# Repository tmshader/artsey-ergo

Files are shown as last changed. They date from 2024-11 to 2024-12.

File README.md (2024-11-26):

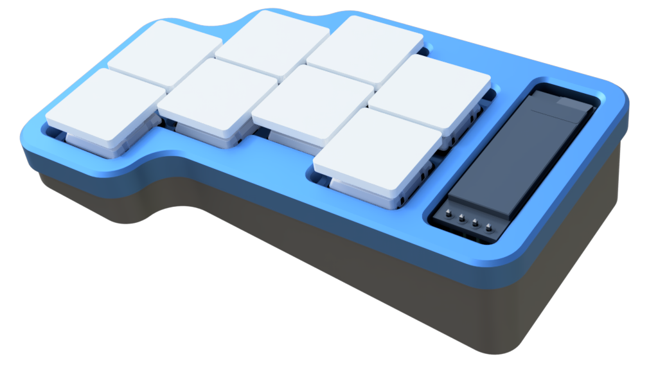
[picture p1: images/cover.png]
Artsey Ergo


# Artsey Ergo
A 3D printable ergonomic wireless Artsey-based keyboard running ZMK.

## Features:
- NRF52840 chip for fast communication over BLE
- USB-C for charging, updating and communication instead of BLE
- Slightly modified Artsey 9.0.0 layout
- 128x32 OLED display for layers, battery status, time and other fun stuff
- Hotswappable choc v1 swiches
- Easily printable case

## Try or modify the project

Modify `ergogen/config.yaml` or use the provided config.

Run ergogen to create the base files:
```bash
ergogen ./ergogen -o .
```

This creates an `outlines` and a `pcbs` folder:
- The `pcbs` folder contains the starting point from which we can start routing and modifying the board.
- The `outlines` folder contains a bunch of mechanical drawings in `.dxf` format but the most important for us is `cad.dxf` which we can import into our favourite CAD software (Fusion, FreeCAD, Solidworks, etc.) and start designing a case for the keyboard.

## Upcoming changes
- Choc and MX compatible board versions
- Using the NRF52840 chip instead of a module
- Thread and Zigbee support (why not?)
- OTA Updates

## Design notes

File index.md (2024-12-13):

---
layout: home
---

{% assign cacheBust = site.time | date:'?v=%s' %}








## Table of contents
{: .no_toc}

* TOC
{:toc}

## Renders

### Render Angled



### Render Top



### Render Bottom



## Schematic

### Monochrome

- [Schematic Monochrome PDF]({{ "/documents/artsey_ergo-schematic-mono.pdf" | absolute_url | append: cacheBust }})

### Light

- [Schematic Light PDF]({{ "/documents/artsey_ergo-schematic-default.pdf" | absolute_url | append: cacheBust }})

## Assembly

### Gerber viewer on tracespace.io

[JLCPCB Gerber](https://tracespace.io/view/?boardUrl={{ "export/artsey_ergo-JLCPCB.zip" | absolute_url | append: cacheBust }})

[Panelized JLCPCB Gerber](https://tracespace.io/view/?boardUrl={{ "export/artsey_ergo-panel-JLCPCB.zip" | absolute_url | append: cacheBust }})

### Interactive BOM

Check component locations by hovering over a specific component.
The visual elements might not be precise enough for pcb review but can be very useful since it's possible to pan and zoom.
Not all BOM columns are available here, for datasheet links see BOM below.

[IBOM HTML]({{ "/export/artsey_ergo-ibom.html" | absolute_url | append: cacheBust }})

### BOM

All components with Values, References, Sheetpath and Links to the datasheet.

[BOM HTML]({{ "/export/artsey_ergo-bom.html" | absolute_url | append: cacheBust }})

## Downloads

### JLCPCB

- [JLCPCB Zip]({{ "export/artsey_ergo-JLCPCB.zip" | absolute_url | append: cacheBust }})
- [JLCPCB BOM CSV]({{ "export/artsey_ergo_bom_jlc.csv" | absolute_url | append: cacheBust }})
- [JLCPCB CPL CSV]({{ "export/artsey_ergo_cpl_jlc.csv" | absolute_url | append: cacheBust }})

### Panelized JLCPCB

- [Panelized JLCPCB Zip]({{ "export/artsey_ergo-panel-JLCPCB.zip" | absolute_url | append: cacheBust }})
- [Panelized JLCPCB BOM CSV]({{ "export/artsey_ergo-panel_bom_jlc.csv" | absolute_url | append: cacheBust }})
- [Panelized JLCPCB CPL CSV]({{ "export/artsey_ergo-panel_cpl_jlc.csv" | absolute_url | append: cacheBust }})

### 3D Step

- [3D Step]({{ "/artsey_ergo-3D.step" | absolute_url | append: cacheBust }})

## Report

### ERC

{% include_relative erc_validation.md %}

### DRC

{% include_relative drc_validation.md %}

{% include_relative artsey_ergo-report.md %}

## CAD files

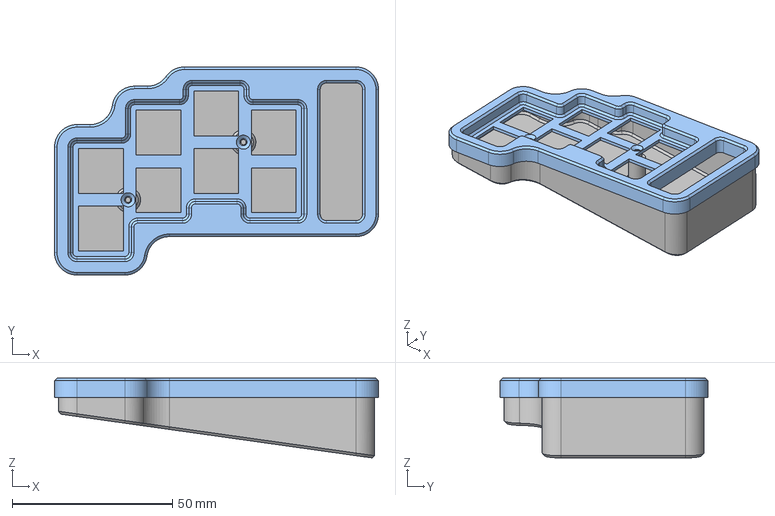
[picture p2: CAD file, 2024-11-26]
hardware/mechanical/STEPs/ArtseyErgo.step
101.2 x 65.0 x 24.9 mm

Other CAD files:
hardware/mechanical/STLs/ArtseyErgo.stl

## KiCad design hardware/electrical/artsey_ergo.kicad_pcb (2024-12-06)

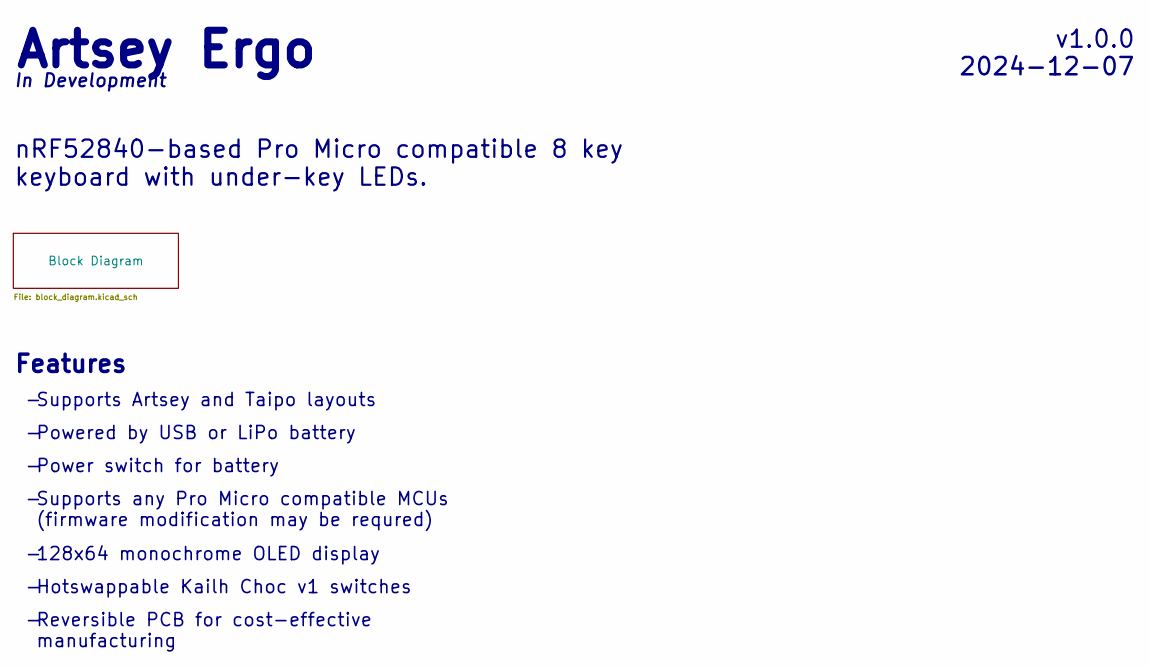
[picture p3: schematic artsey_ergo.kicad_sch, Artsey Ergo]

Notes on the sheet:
Features
Hotswappable Kailh Choc v1 switches
${REVISION}
${ISSUE_DATE}
128x64 monochrome OLED display
Supports any Pro Micro compatible MCUs (firmware modification may be requred)
Supports Artsey and Taipo layouts
${TITLE}
nRF52840-based Pro Micro compatible 8 key keyboard with under-key LEDs.
Powered by USB or LiPo battery
In Development
Reversible PCB for cost-effective manufacturing
Power switch for battery

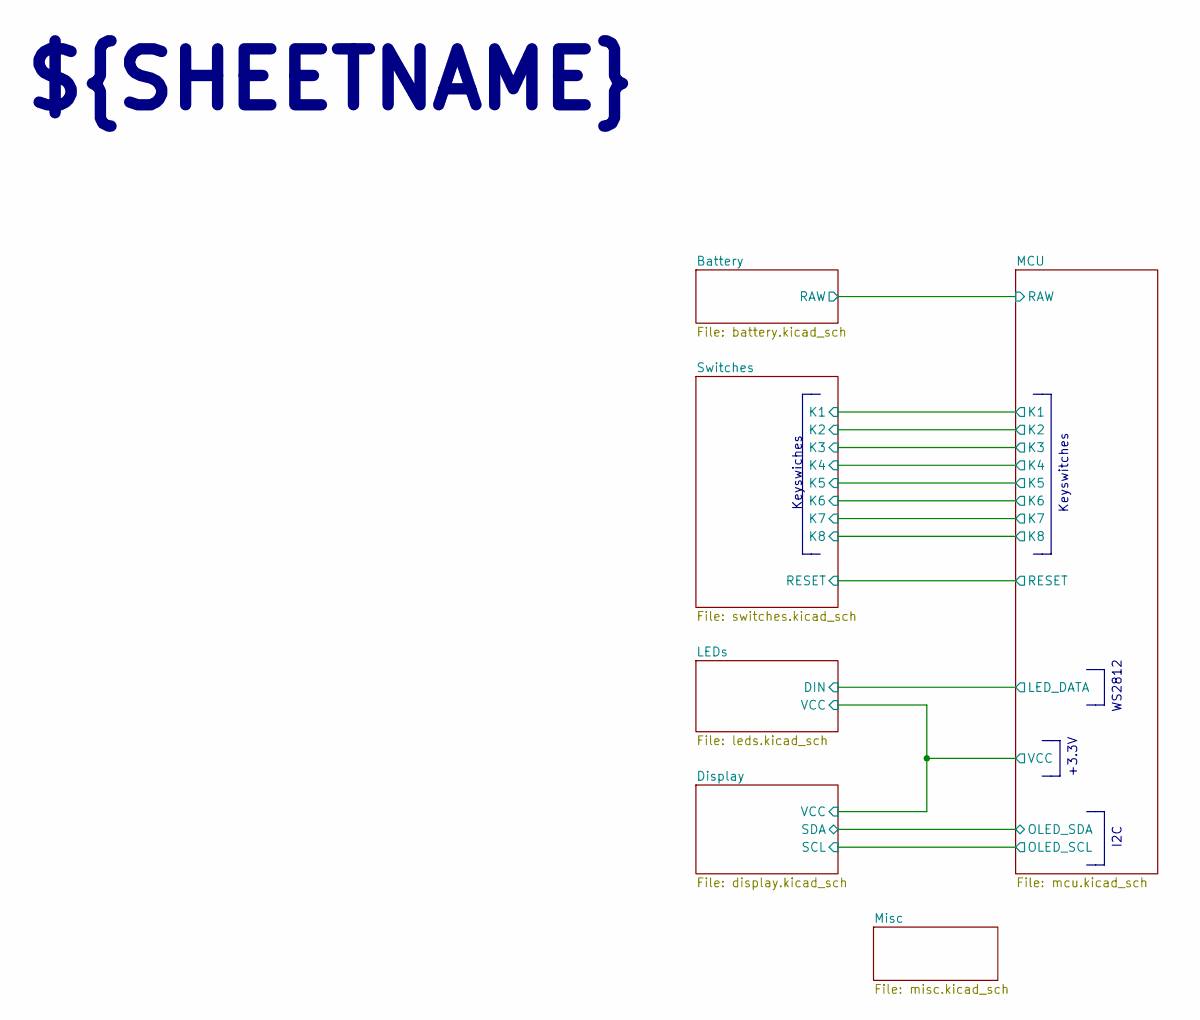
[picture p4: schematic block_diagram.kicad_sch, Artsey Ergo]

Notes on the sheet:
I2C
Keyswiches
+3.3V
${SHEETNAME}
Keyswitches
WS2812

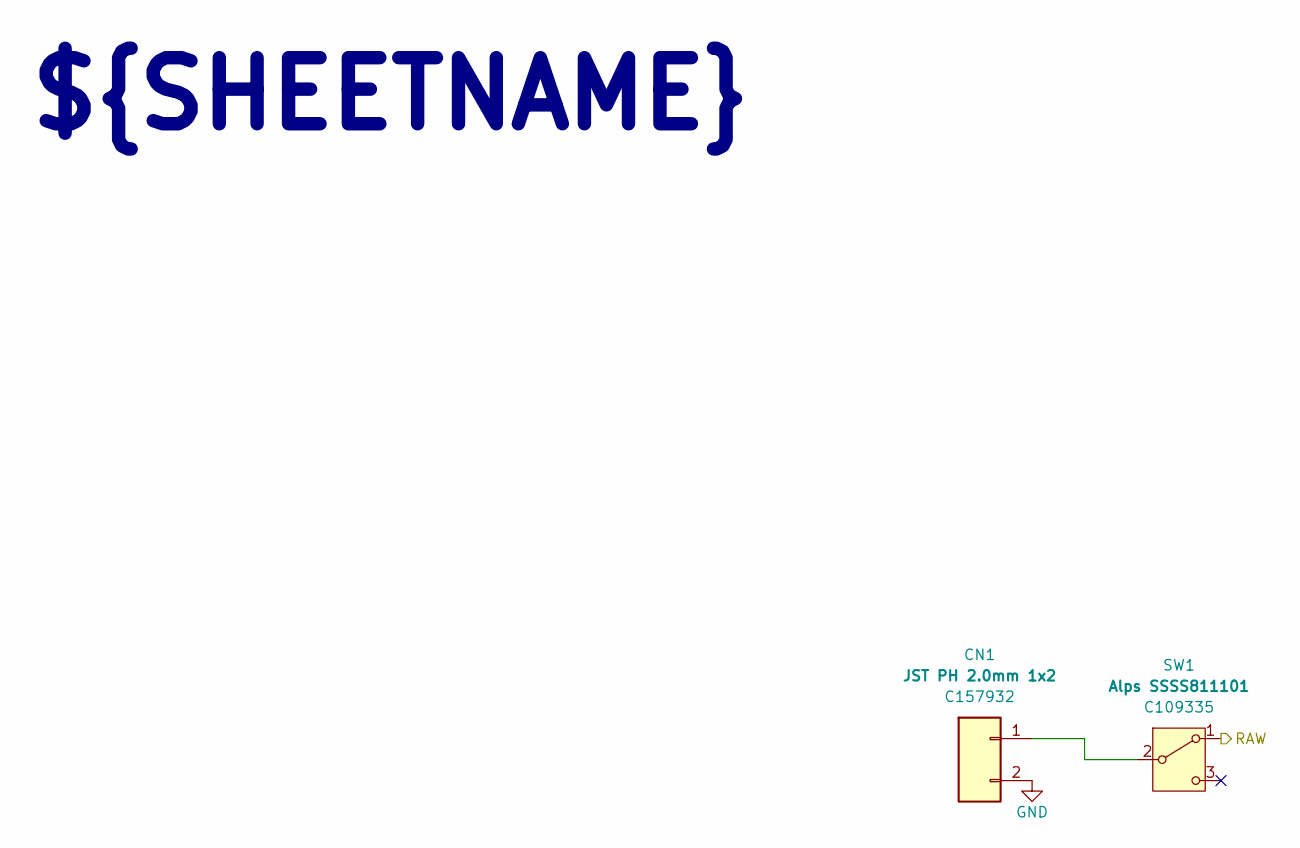
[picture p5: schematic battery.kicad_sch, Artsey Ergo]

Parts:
CN1: JST PH 2.0mm 1x2; battery_connector_jst_ph_2; LCSC C157932
SW1: Alps SSSS811101; power_switch_smd_side; LCSC C109335

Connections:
/Block Diagram/Battery/RAW: SW1.1 (A); also elsewhere on the board
GND: CN1.2; also elsewhere on the board
unnamed: CN1.1, SW1.2 (B)

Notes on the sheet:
${SHEETNAME}

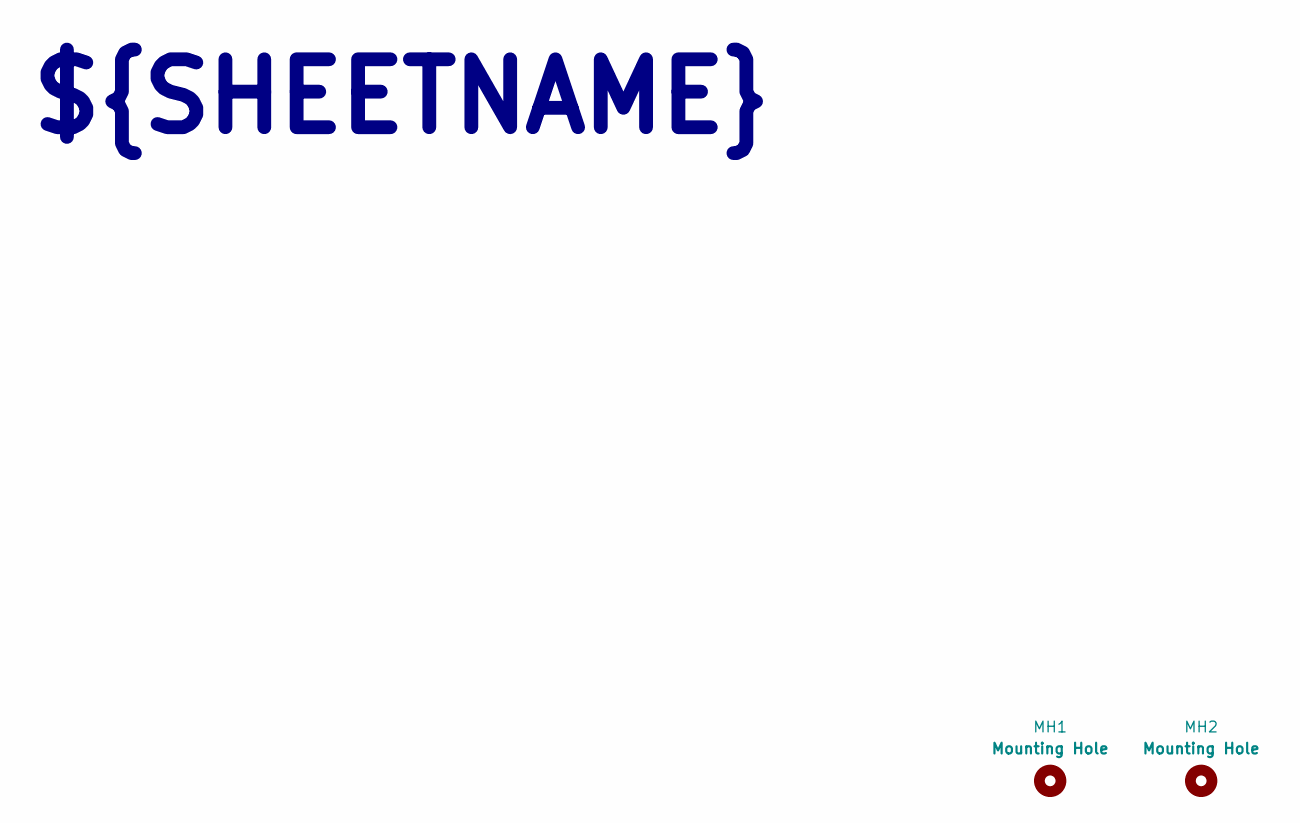
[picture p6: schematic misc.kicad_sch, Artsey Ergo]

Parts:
MH1, MH2: Mounting Hole; mounting_hole

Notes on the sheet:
${SHEETNAME}

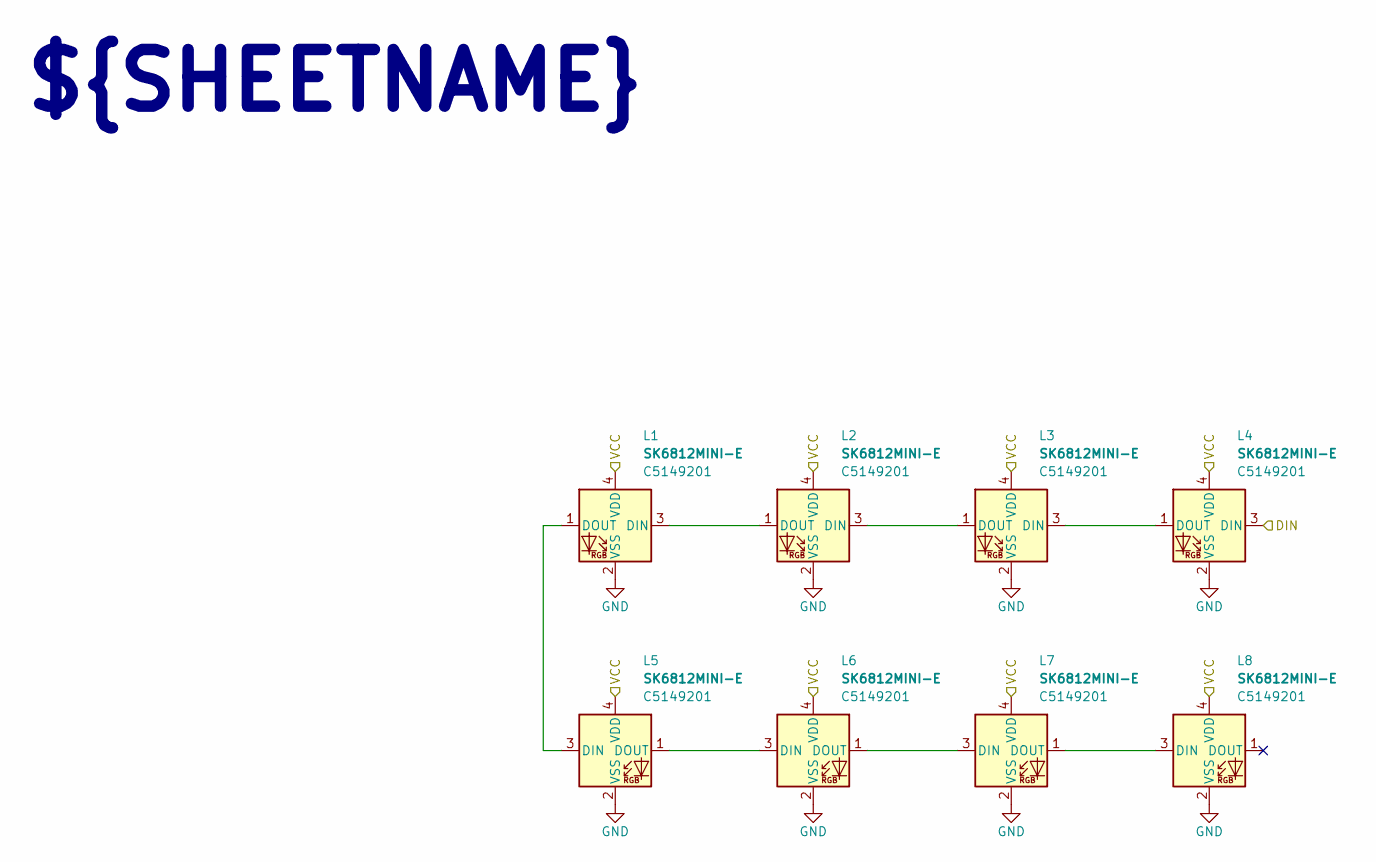
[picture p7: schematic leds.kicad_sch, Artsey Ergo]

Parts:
L1, L2, L3, L4, L5, L6, L7, L8: SK6812MINI-E; led_SK6812mini-e (per-key, reversible); LCSC C5149201

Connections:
/Block Diagram/Display/VCC: L1.4 (VDD), L2.4 (VDD), L3.4 (VDD), L4.4 (VDD), L5.4 (VDD), L6.4 (VDD), L7.4 (VDD), L8.4 (VDD); also elsewhere on the board
/Block Diagram/LEDs/DIN: L4.3 (DIN); also elsewhere on the board
GND: L1.2 (VSS), L2.2 (VSS), L3.2 (VSS), L4.2 (VSS), L5.2 (VSS), L6.2 (VSS), L7.2 (VSS), L8.2 (VSS); also elsewhere on the board
unnamed: L1.3 (DIN), L2.1 (DOUT)
unnamed: L1.1 (DOUT), L5.3 (DIN)
unnamed: L2.3 (DIN), L3.1 (DOUT)
unnamed: L3.3 (DIN), L4.1 (DOUT)
unnamed: L5.1 (DOUT), L6.3 (DIN)
unnamed: L6.1 (DOUT), L7.3 (DIN)
unnamed: L7.1 (DOUT), L8.3 (DIN)

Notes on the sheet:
${SHEETNAME}

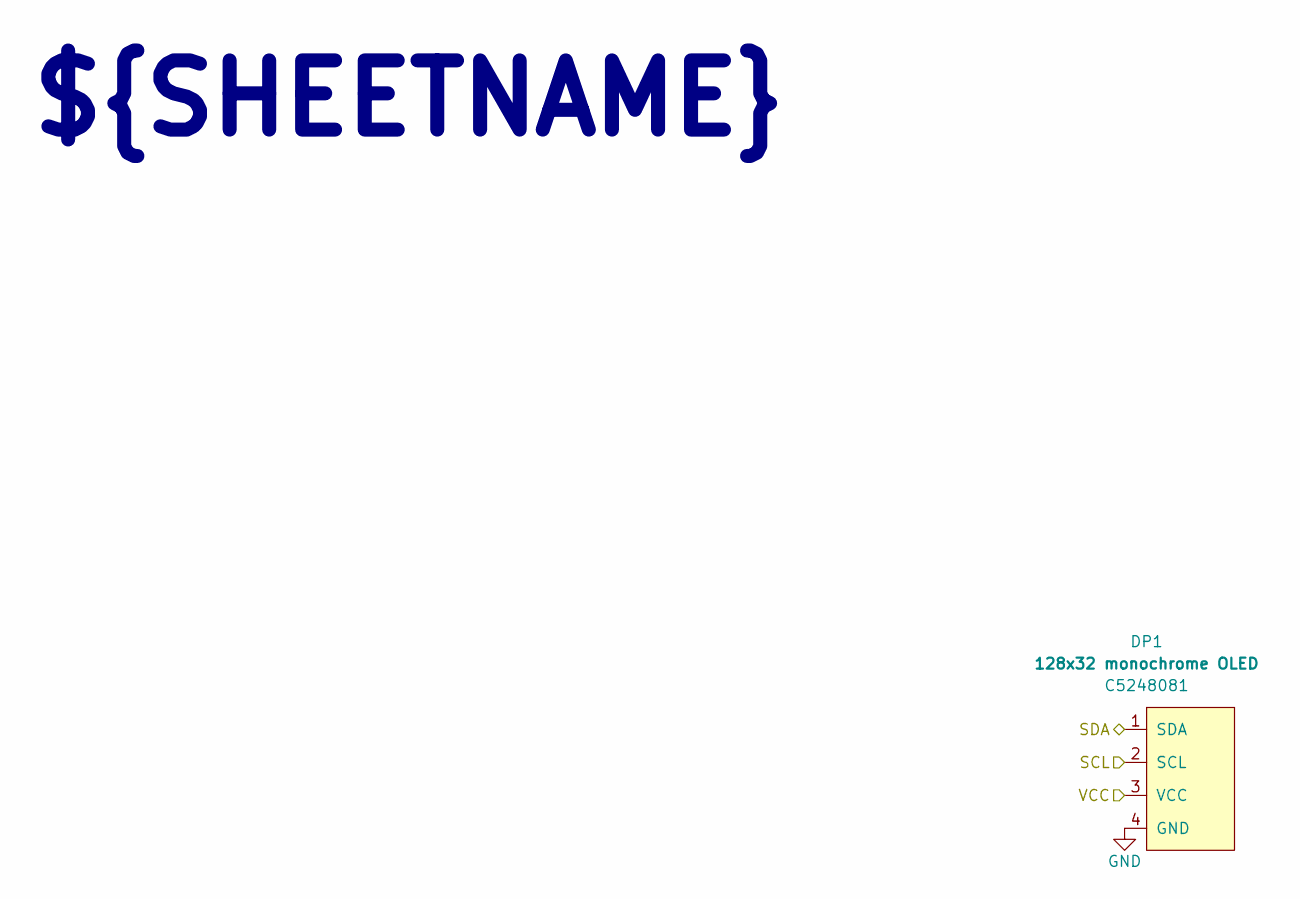
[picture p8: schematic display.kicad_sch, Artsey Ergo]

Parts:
DP1: 128x32 monochrome OLED; display_ssd1306; LCSC C5248081

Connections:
/Block Diagram/Display/SCL: DP1.2 (SCL); also elsewhere on the board
/Block Diagram/Display/SDA: DP1.1 (SDA); also elsewhere on the board
/Block Diagram/Display/VCC: DP1.3 (VCC); also elsewhere on the board
GND: DP1.4 (GND); also elsewhere on the board

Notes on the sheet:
${SHEETNAME}

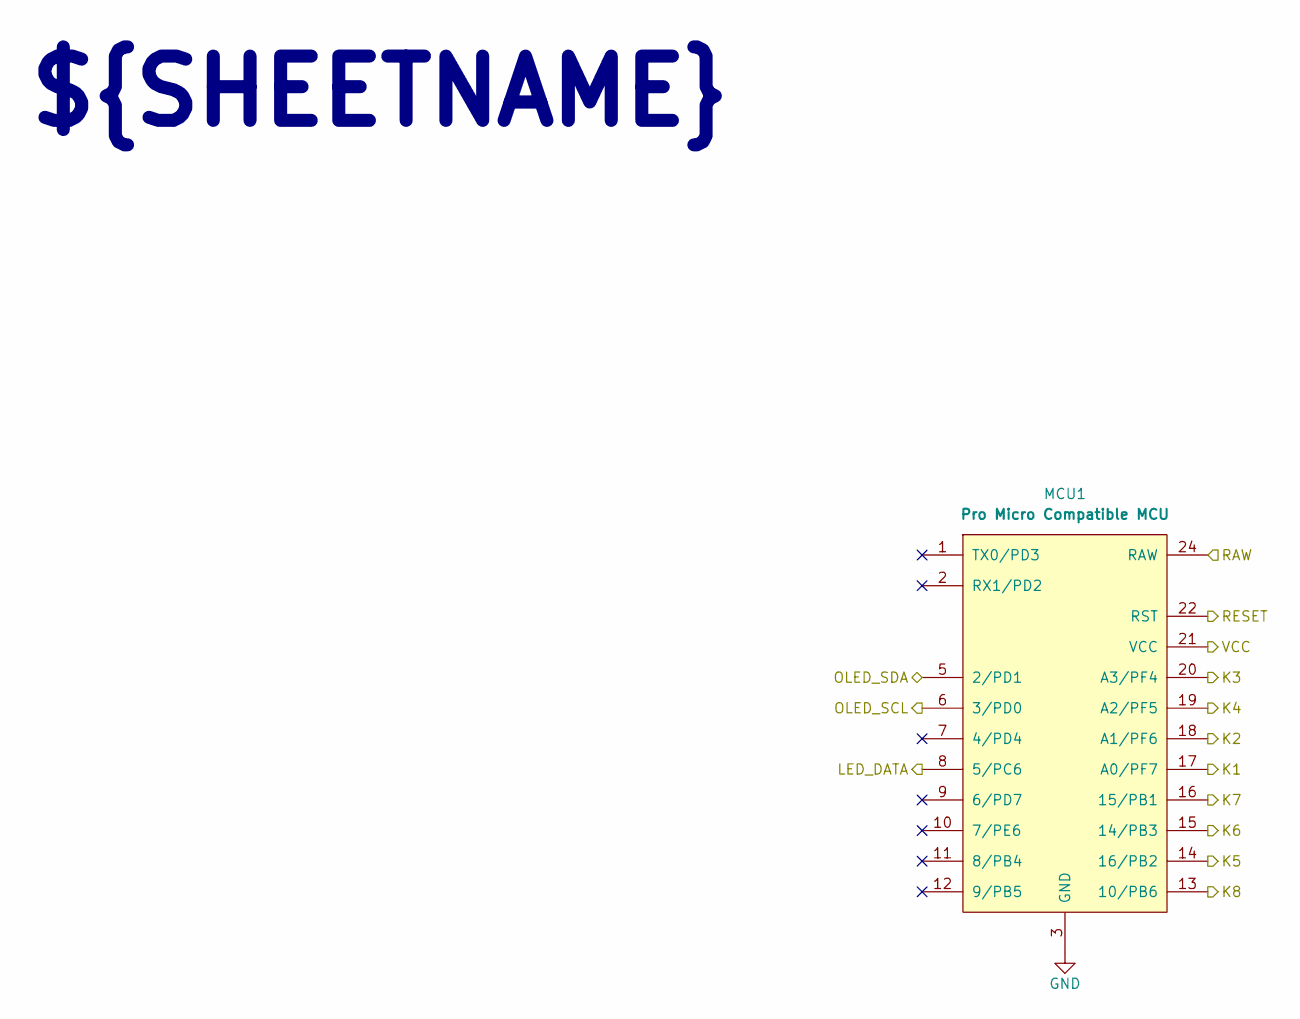
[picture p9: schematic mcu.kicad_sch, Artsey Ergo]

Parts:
MCU1: Pro Micro Compatible MCU; mcu_nice_nano

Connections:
/Block Diagram/Battery/RAW: MCU1.24 (RAW); also elsewhere on the board
/Block Diagram/Display/SCL: MCU1.6 (3/PD0); also elsewhere on the board
/Block Diagram/Display/SDA: MCU1.5 (2/PD1); also elsewhere on the board
/Block Diagram/Display/VCC: MCU1.21 (VCC); also elsewhere on the board
/Block Diagram/LEDs/DIN: MCU1.8 (5/PC6); also elsewhere on the board
/Block Diagram/MCU/K1: MCU1.17 (A0/PF7); also elsewhere on the board
/Block Diagram/MCU/K2: MCU1.18 (A1/PF6); also elsewhere on the board
/Block Diagram/MCU/K3: MCU1.20 (A3/PF4); also elsewhere on the board
/Block Diagram/MCU/K4: MCU1.19 (A2/PF5); also elsewhere on the board
/Block Diagram/MCU/K5: MCU1.14 (16/PB2); also elsewhere on the board
/Block Diagram/MCU/K6: MCU1.15 (14/PB3); also elsewhere on the board
/Block Diagram/MCU/K7: MCU1.16 (15/PB1); also elsewhere on the board
/Block Diagram/MCU/K8: MCU1.13 (10/PB6); also elsewhere on the board
/Block Diagram/MCU/RESET: MCU1.22 (RST); also elsewhere on the board
GND: MCU1.3 (GND), MCU1.4 (GND), MCU1.23 (GND); also elsewhere on the board

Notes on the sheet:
${SHEETNAME}

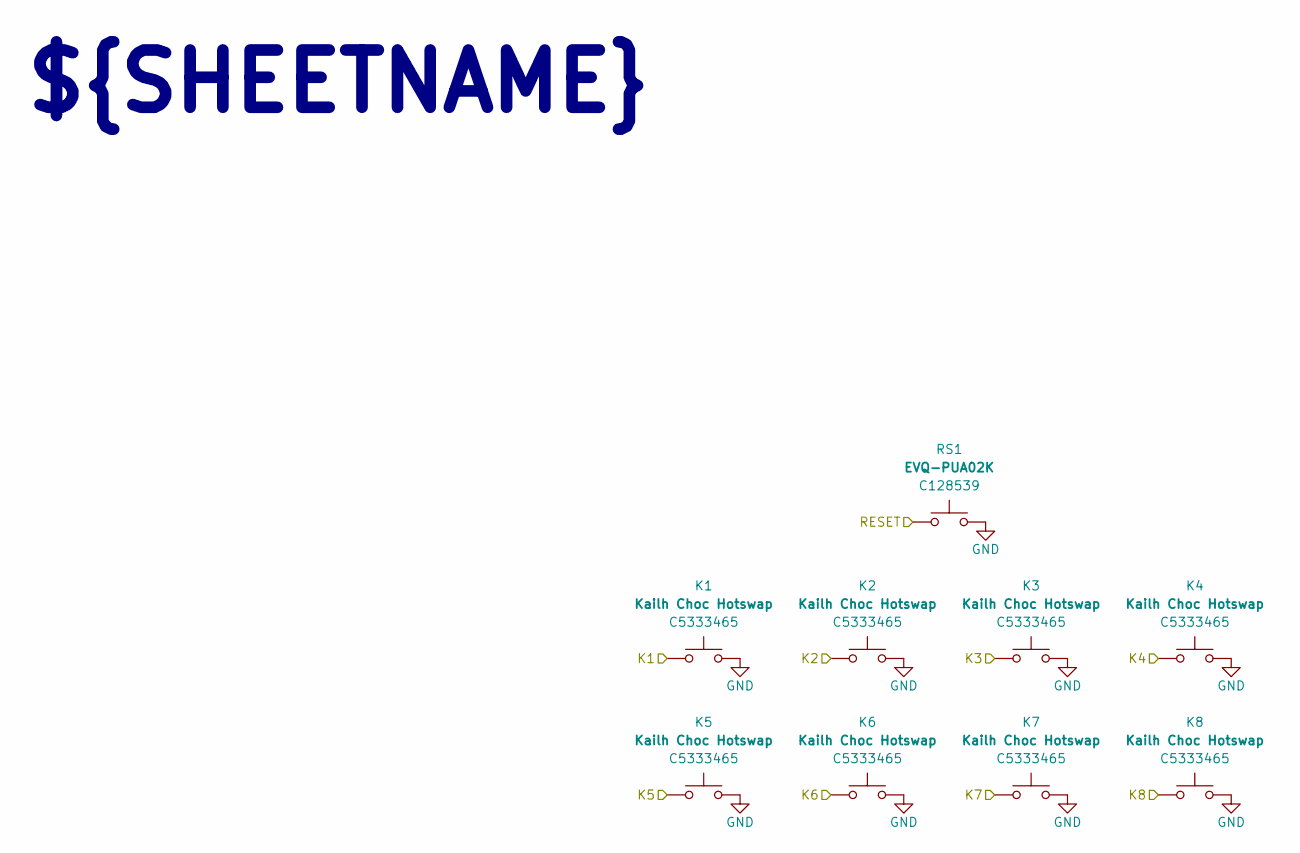
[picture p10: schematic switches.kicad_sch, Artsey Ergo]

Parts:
K1, K2, K3, K4, K5, K6, K7, K8: Kailh Choc Hotswap; switch_choc_v1_v2; LCSC C5333465
RS1: EVQ-PUA02K; reset_switch_smd_side; LCSC C128539

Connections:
/Block Diagram/MCU/K1: K1.1; also elsewhere on the board
/Block Diagram/MCU/K2: K2.1; also elsewhere on the board
/Block Diagram/MCU/K3: K3.1; also elsewhere on the board
/Block Diagram/MCU/K4: K4.1; also elsewhere on the board
/Block Diagram/MCU/K5: K5.1; also elsewhere on the board
/Block Diagram/MCU/K6: K6.1; also elsewhere on the board
/Block Diagram/MCU/K7: K7.1; also elsewhere on the board
/Block Diagram/MCU/K8: K8.1; also elsewhere on the board
/Block Diagram/MCU/RESET: RS1.1; also elsewhere on the board
GND: K1.2, K2.2, K3.2, K4.2, K5.2, K6.2, K7.2, K8.2, RS1.2; also elsewhere on the board

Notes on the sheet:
${SHEETNAME}

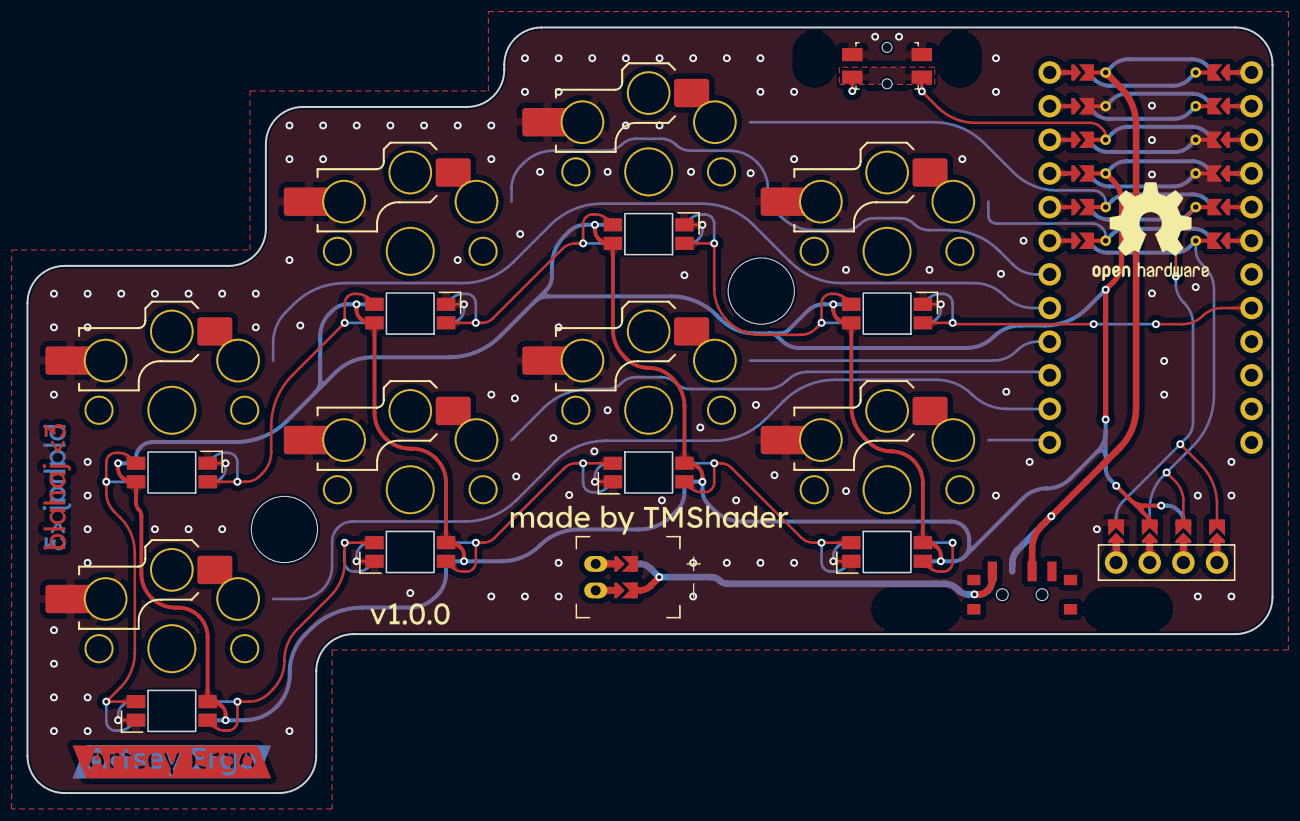
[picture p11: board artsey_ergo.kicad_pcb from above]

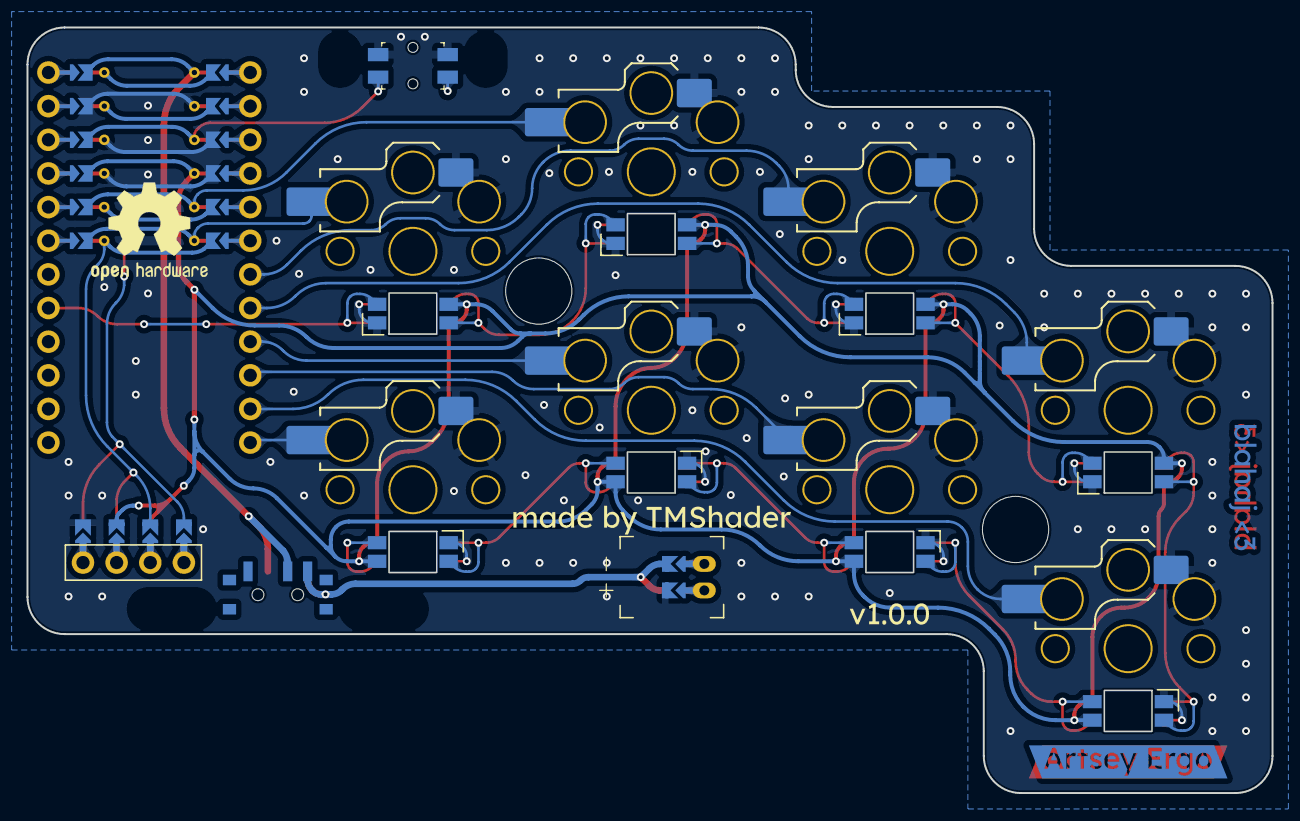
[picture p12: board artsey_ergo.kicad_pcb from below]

Board: 2 copper layers, 94.0 x 57.8 mm, 24 parts (19 on the bottom side), 23 nets.

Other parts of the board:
OL1: Value; Outline

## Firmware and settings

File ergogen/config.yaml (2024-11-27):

meta:
  engine: 4.1.0
  version: 1.0.0
  author: TMShader

units:
  keycap: 17
  stagger_unit: cx/3

  orig: cx/2

  # Sheet size: 420x297
  centerShiftX: -2cx
  centerShiftY: -cx

  sheetShiftX: 420/2
  sheetShiftY: -(297/2)

  border_size: 5

  dP: 1
  dsX: 12.2
  dsY: 2cx + stagger_unit - dP + (cx-keycap)
  dpX: dsX/2 + cx/2 + border_size + dP/2 + (cx-keycap)/2
  dpY: stagger_unit/2 + cx/2

  mcuX: 18

points:
  key:
    padding: cx
    spread: cx
    width: keycap
    height: keycap
  zones:
    matrix:
      columns:
        pinky:
          rows.home:
            net: "key_{{name}}"
            led_in: "led_{{name}}"
            led_out: led_matrix_ring_home
          rows.top:
            net: "key_{{name}}"
            led_in: "led_{{name}}"
            led_out: led_matrix_pinky_home
        ring:
          key.stagger: stagger_unit*2
          rows.home:
            net: "key_{{name}}"
            led_in: "led_{{name}}"
            led_out: led_matrix_middle_home
          rows.top:
            net: "key_{{name}}"
            led_in: "led_{{name}}"
            led_out: led_matrix_pinky_top
        middle:
          key.stagger: stagger_unit
          rows.home:
            net: "key_{{name}}"
            led_in: "led_{{name}}"
            led_out: led_matrix_index_home
          rows.top:
            net: "key_{{name}}"
            led_in: "led_{{name}}"
            led_out: led_matrix_ring_top
        index:
          key.stagger: -stagger_unit
          rows.home:
            net: "key_{{name}}"
            led_in: "led_{{name}}"
            led_out: x
          rows.top:
            net: "key_{{name}}"
            led_in: LED_DIN
            led_out: led_matrix_middle_top
      anchor.shift: [centerShiftX + sheetShiftX, centerShiftY + sheetShiftY]

outlines:
  display:
    - what: rectangle
      where: matrix_index_home
      adjust.shift: [dpX, dpY]
      size: [dsX, dsY]

  display_1:
    - what: rectangle
      where: matrix_index_home
      adjust.shift: [dpX, dpY]
      size: [dsX + dP, dsY + dP]

  keys:
    - what: rectangle
      where: true
      size: [keycap, keycap]
      fillet: 2
    - what: outline
      name: display
      operation: stack
      fillet: 1

  board_base:
    - what: rectangle
      where: true
      size: [cx, cx]
      expand: (cx-keycap)/2
      joints: 1

  board:
    - name: board_base
    - what: rectangle
      where: matrix_index_home
      size: [cx*2 + border_size + dsX + dP + (cx-keycap)/2, cx*2 + stagger_unit + cx-keycap]
      adjust.shift: [0.35, dpY]

  pcb_raw:
    - what: outline
      name: board
      expand: border_size - 1.2*3
      joints: 1

  pcb:
    - what: outline
      name: pcb_raw
      fillet: 2.8

  cad_raw:
    - what: outline
      name: board
      expand: border_size
      joints: 1
    - what: rectangle
      where: true
      size: [14, 14]
      operation: stack
    - what: outline
      name: display_1
      operation: stack
    - what: outline
      name: board_base
      operation: stack

  cad_dwg:
    - what: outline
      name: board
      expand: border_size - 1.2*2
      joints: 1
    - name: cad_raw
      operation: stack

  cad:
    raw:
      name: cad_raw
      adjust.shift: [-sheetShiftX, -sheetShiftY]
    hole1: &cad_hole_params
      what: circle
      radius: 3.8/2
      adjust.shift: [-sheetShiftX, -sheetShiftY]
      where: &hole1
        ref: matrix_pinky_top
        shift: [cx/2 - 0.5, -cx/2]
    hole2:
      <<: *cad_hole_params
      where: &hole2
        ref: matrix_middle_top
        shift: [cx/2 - 0.5, -cx/2]

  pcb_cad:
    raw:
      name: pcb
      adjust.shift: [-sheetShiftX, -sheetShiftY]
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

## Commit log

2024-11-21 Update case image and add STL file, fix configuration errors
    [case.stl]
2024-11-25 Fix dimensions and heavily modify layout, generation process and case style
    [case.stl]
2024-11-26 Finish v1 PCB, clean up repo structure, tidy up ergogen config files, add LICENSE, add CAD and 3D models
    [ArtseyErgo.step, ArtseyErgo.stl, artsey_ergo.kicad_pcb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]
2024-11-26 Fix clearance issues with battery connector and ground fill
    [artsey_ergo.kicad_pcb]
2024-11-26 Fix DRC errors with battery connector
    [artsey_ergo.kicad_pcb]
2024-11-27 Move LED data and I2C pins to high speed pin to avoid RF interference
    [artsey_ergo.kicad_pcb]
2024-12-05 Clean up and modify PCB, create Schematic, prepare for documentation generation
    [artsey_ergo.kicad_pcb, artsey_ergo.kicad_sch, battery.kicad_sch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]
2024-12-05 Setup KiBot and GitHub Pages deploy
    [artsey_ergo.kicad_pcb]
2024-12-06 Add panelized JLCPCB build, make actions faster by skipping rendering with a variable
    [artsey_ergo.kicad_pcb]
2024-12-06 Fix small errors in schematic and pcb
    [artsey_ergo.kicad_pcb, artsey_ergo.kicad_sch, battery.kicad_sch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]
2024-12-10 Remove schematic renaming
2025-01-02 Fix pins and LEDs
2025-01-02 Fix LED
2025-01-02 Revert LED config
2025-01-10 LED config testing
2025-01-10 Fix pin order
